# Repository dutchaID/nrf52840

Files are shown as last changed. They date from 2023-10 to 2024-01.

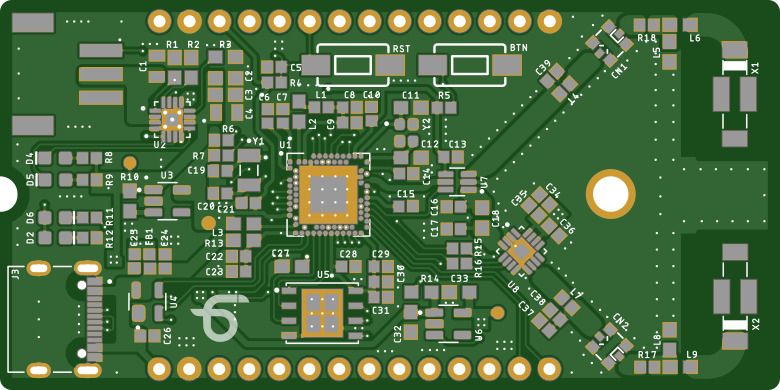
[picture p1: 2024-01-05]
top.jpg

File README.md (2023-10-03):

# Dokumentasi Board NRF52840 V1.0723

﷽

Semoga sehat selalu untuk kita semua.
.
.
.
.
.

# Flash bootloader NRF52840

Bootloader diperlukan karena SOC **NRF52840** dari JLC masih kosong, jadi  fitur-fitur yang ada seperti DFU USB tidak dapat terbaca di PC.

File bootloader bisa menggunakan apa saja, sebagai contoh saya menggunakan bootloader **NRF52840 DK** (PCA10056), kemudian semua config pinout mengikuti board tersebut.

## Peralatan Tempur

- OpenOCD, [gas di sini](https://openocd.org/).
- ST-link V.2
- File bootloader PCA10056
- Arduino IDE, [gas di sini](https://www.arduino.cc/en/software).
- Kabel USB type C

## Langkah-Langkah

1. Install semua peralatan tempurnya. Pastikan sudah **OK** ya...
2. Hubungkan board `NRF52840` dengan `ST-Link V.2` via SWD.
	> */3V3*
	> */GND*
	> */SWCLK*
	> */SWDIO/*
3. Buka Terminal:
    - Cek versi `openocd`,
       >*> openocd -v*
    - Run `openocd`, direktori nya disesuaikan ya...
       >*> openocd -f share/openocd/scripts/interface/stlink.cfg -f share/openocd/scripts/target/nrf52.cfg*
    - `Openocd` sekarang sudah running. Sekarang kita buka terminal lagi untuk menggunakan `telnet`.
       >*> telnet localhost 4444*
    - `Stop execution` bisa gunakan, 
       > *> halt*
    - Hapus `flash` memory,
       > *> nrf5 mass_erase*
    - `Flash NRF52840`,
       > *> program /your/path/to/the/pca10056_bootloader-0.6.2_s140_6.1.1.hex verify*
    - Resume the execution,
       > *> resume*
       
4. Jika berhasil maka pada `Device Manager`, board akan terbaca sebagai *`USB Serial Device(COM...)`*
5. Untuk masuk ke mode `DFU` tekan 2 kali tombol `reset`.

## Pemrograman NRF52840 menggunakan Arduino IDE
1. Buka Arduino IDE, lalu pilih tab `File` dan pilih `Preferences` dan masukkan URL berikut:
    >*https://adafruit.github.io/arduino-board-index/package_adafruit_index.json*
2. Restart Arduino IDE.
3. Pilih `Tools` > `Board` > `Board Manager`. Kemudian pada textbox filter pencarian filter dengan `NRF` dan install `Arduino nRF52 Boars` dan `Adafruit nRF52`.
4. Setelah selesai, silahkan digasken ngodingnya... (saya mencoba dengan program template `bleuart`).....

## Config Pin Board NRF52840

- On board LED `P0.11`, active `LOW`.
- On board button `P1.10`, active `LOW`.
- Switch RF PE4259 `P1.06`, active `HIGH`, lebih detail lihat datasheet.
- Front end RF RFX2401C, RX Enable `P1.04` dan TX Enable `P1.05`, lebih detail lihat datasheet.

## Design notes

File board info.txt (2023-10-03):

> Bluefruit 52 HW Info
 
> MAC Address: E3:32:7:18:24:33
> Device ID  : A3299C384744D933
> MCU Variant: nRF52840 0x41414430
> Memory     : Flash = 1024 KB, RAM = 256 KB

> led P0.11 > 11
> btn P1.10 > 42

> swrf P1.06 > 38 
> txen P1.05 > 37
> rxen P1.04 > 36

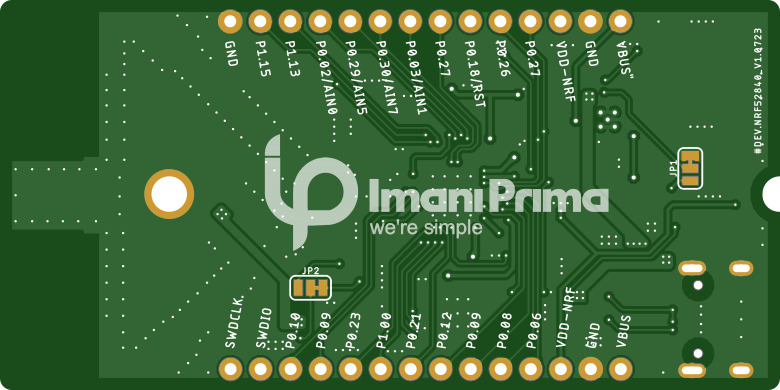
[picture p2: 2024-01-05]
bottom.jpg

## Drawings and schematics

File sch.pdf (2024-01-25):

# P0.02/AIN0 P⁰.02/AIN⁰

# P0.03/AIN1 P⁰.03/AIN¹

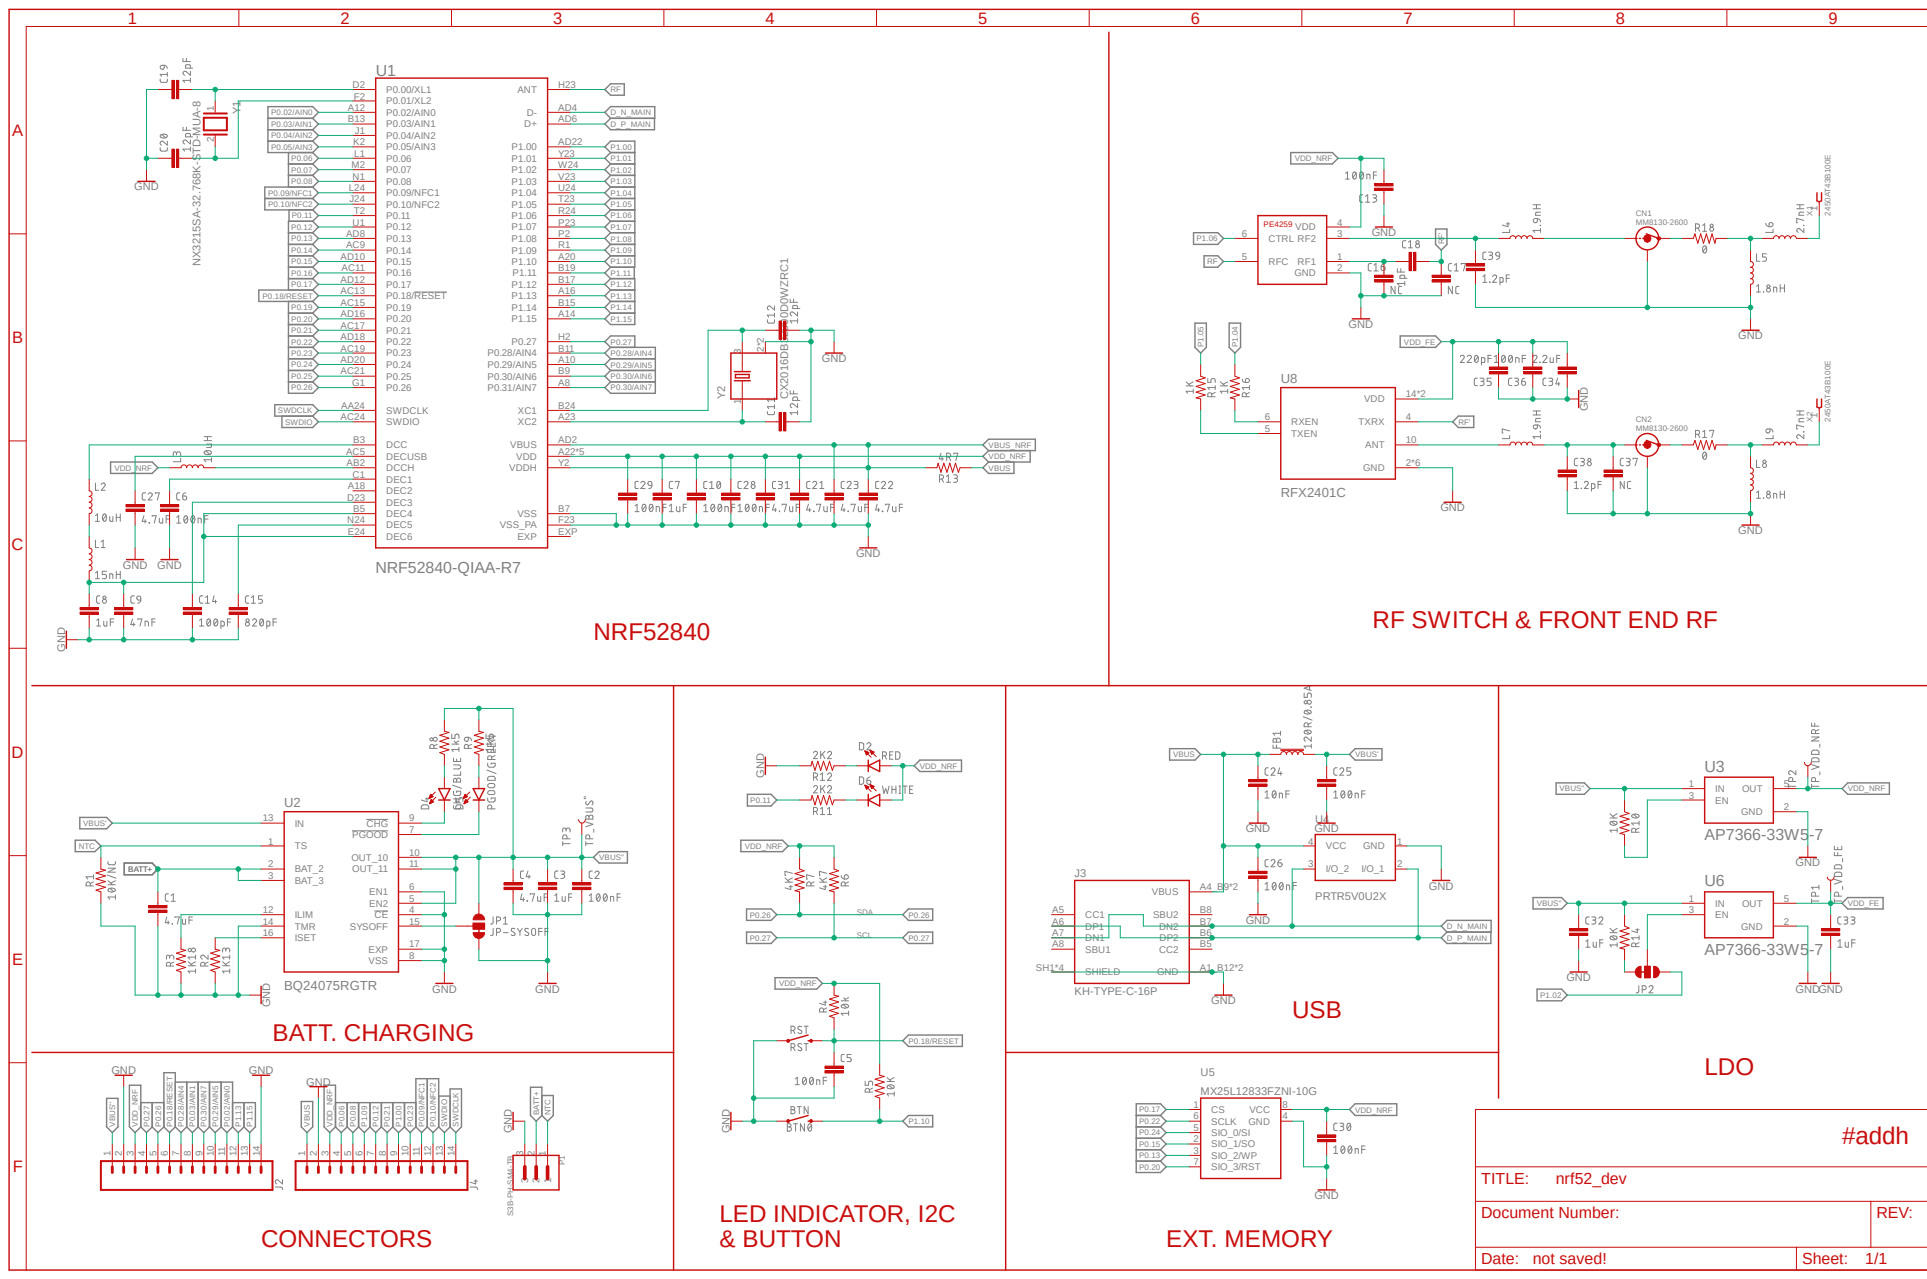
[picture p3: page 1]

P0.04/AIN2 | P0.05/AIN3 K2 | PE4259 A

GND GND

VDD_NRF | DEC1 C1

GND S³B⁻PH⁻SM⁴⁻TB GND

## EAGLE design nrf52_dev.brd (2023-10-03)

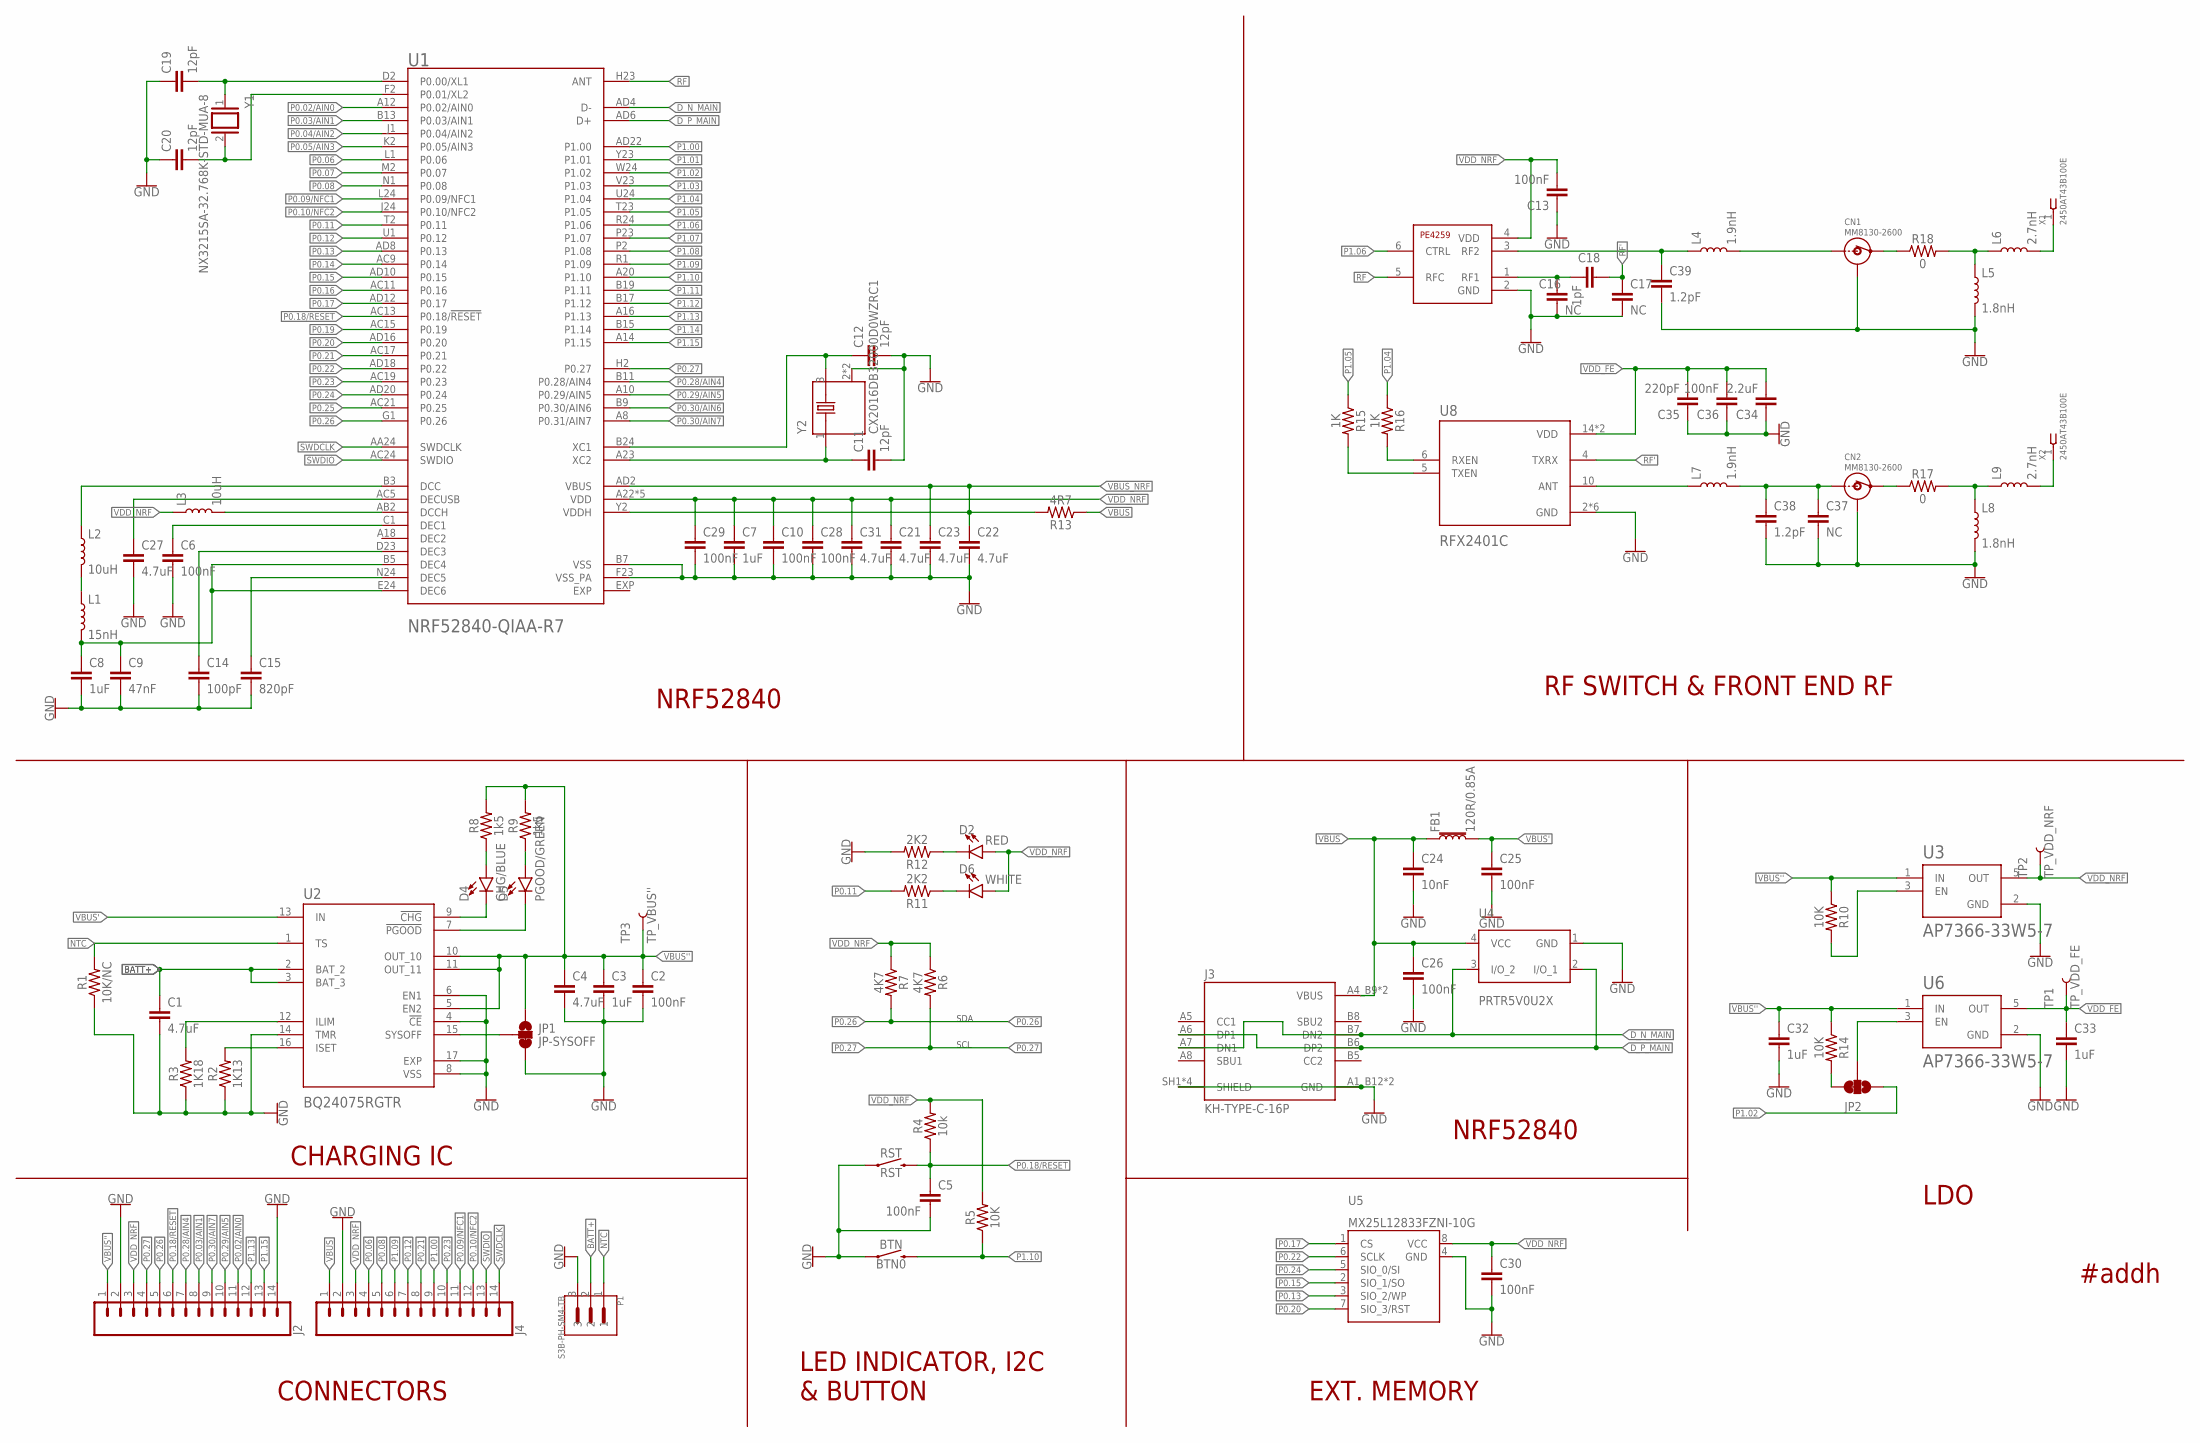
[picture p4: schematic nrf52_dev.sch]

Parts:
BTN: BTN0; TACTILE_SWITCH_SMD_6.0X3.5MM
C1, C4: 4.7uF; 0805
C2: 100nF; 0603
C3, C32, C33: 1uF; 0603
C5, C6, C10, C13, C25, C26, C28, C29, C30, C36: 100nF; 0402
C7, C8: 1uF; 0402
C9: 47nF; 0402
C11, C12: 12pF; 0603
C14: 100pF; 0402
C15: 820pF; 0402
C16, C17, C37: NC; 0402
C18: 1pF; 0603
C19, C20: 12pF; 0402
C21, C22, C23, C31: 4.7uF; 0402
C24: 10nF; 0402
C27: 4.7uF; 0603
C34: 2.2uF; 0402
C35: 220pF; 0402
C38, C39: 1.2pF; 0402
CN1, CN2: MM8130-2600
D2: RED; LED-0603
D4: CHG/BLUE; LED-0603
D5: PGOOD/GREEN; LED-0603
D6: WHITE; LED-0603
FB1: 120R/0.85A; 0402
J2, J4: CONN_14NO_SILK; 1X14_NO_SILK
J3: KH-TYPE-C-16P; KINGHELM_KH-TYPE-C-16P
JP1: JP-SYSOFF; SMT-JUMPER_3_1-NC_TRACE_SILK
JP2: JP_EN1; SMT-JUMPER_3_1-NC_TRACE_SILK
L1: 15nH; 0402
L2, L3: 10uH; 0603
L4, L7: 1.9nH; 0402
L5, L8: 1.8nH; 0603
L6, L9: 2.7nH; 0603
P1: S3B-PH-SM4-TB; JST_S3B-PH-SM4-TB
R1: 10K/NC; 0603
R2: 1K13; 0603
R3: 1K18; 0603
R4: 10k; 0402
R5: 10K; 0402
R6, R7: 4K7; 0402
R8, R9: 1k5; 0402
R10, R14: 10K; 0603
R11, R12: 2K2; 0402
R13: 4R7; 0603
R15, R16: 1K; 0402
R17, R18: 0; 0402
RST: RST; TACTILE_SWITCH_SMD_6.0X3.5MM
TP1: TP_VDD_FE; PAD.03X.04
TP2: TP_VDD_NRF; PAD.03X.04
TP3: TP_VBUS''; PAD.03X.04
U1: NRF52840-QIAA-R7; NORDIC_NRF52840-QIAA-R7
U2: BQ24075RGTR; QFN50P300X300X100-17N
U3, U6: AP7366-33W5-7; SOT95P285X140-5N
U4: PRTR5V0U2X; SOT190P230X110-4N
U5: MX25L12833FZNI-10G; SON127P500X600X80-9N
U7: PE4259; SOT65P210X110-6N
U8: RFX2401C; QFN50P300X300X60-17N
X1, X2: 2450AT43B100E; 2450AT43B100
Y1: NX3215SA-32.768K-STD-MUA-8; XTAL_NX3215SA-32.768K-STD-MUA-8
Y2: CX2016DB32000D0WZRC1; OSCCC200X160X45N

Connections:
BATT+: C1.1, P1.2, U2.2 (BAT_2), U2.3 (BAT_3)
DEC2: U1.A18 (DEC2)
D_N_MAIN: J3.A7 (DN1), J3.B7 (DN2), U1.AD4 (D-), U4.3 (I/O_2)
D_P_MAIN: J3.A6 (DP1), J3.B6 (DP2), U1.AD6 (D+), U4.2 (I/O_1)
EXP: U1.EXP
GND: BTN.1, C1.2, C2.2, C3.2, C4.2, C5.2, C6.2, C7.2, C8.2, C9.2, C10.2, C11.2, C12.2, C13.1, C14.2, C15.2, C16.2, C17.2, C19.1, C20.1, C21.2, C22.2, C23.2, C24.2, C25.2, C26.2, C27.2, C28.2, C29.2, C30.2, C31.2, C32.2, C33.2, C34.1, C35.1, C36.1, C37.2, C38.2, C39.2, CN1.1, CN1.2, CN1.3, CN1.4, CN2.1, CN2.2, CN2.3, CN2.4, J2.2, J2.14, J3.A1_B12 (GND), J3.A12_B1 (GND), J3.SH1 (SHIELD), J3.SH2 (SHIELD), J3.SH3 (SHIELD), J3.SH4 (SHIELD), J4.2, JP1.3, L5.2, L8.2, P1.3, R1.1, R2.1, R3.1, R12.2, RST.1, U1.B7 (VSS), U1.F23 (VSS_PA), U2.4 (!CE), U2.6 (EN1), U2.8 (VSS), U2.14 (TMR), U2.17 (EXP), U3.2 (GND), U4.1 (GND), U5.4 (GND), U6.2 (GND), U7.2 (GND), U8.2 (GND), U8.3 (GND), U8.8 (GND), U8.9 (GND), U8.11 (GND), U8.17 (GND), Y2.2 (GND), Y2.4 (GND)
unnamed: JP2.2, U6.3 (EN)
unnamed: C27.1, U1.AC5 (DECUSB)
unnamed: JP2.3, R14.2
unnamed: D4.C, U2.9 (!CHG)
unnamed: L3.2, U1.AB2 (DCCH)
unnamed: L1.1, L2.2
unnamed: C6.1, U1.C1 (DEC1)
unnamed: L2.1, U1.B3 (DCC)
unnamed: C20.2, U1.F2 (P0.01/XL2), Y1.2
unnamed: C14.1, U1.D23 (DEC3)
unnamed: C15.1, U1.N24 (DEC5)
unnamed: C8.1, C9.1, L1.2, U1.B5 (DEC4), U1.E24 (DEC6)
unnamed: C19.2, U1.D2 (P0.00/XL1), Y1.1
unnamed: C11.1, U1.A23 (XC2), Y2.1 (HOT_1)
unnamed: C12.1, U1.B24 (XC1), Y2.3 (HOT_3)
unnamed: R16.2, U8.6 (RXEN)
unnamed: R15.2, U8.5 (TXEN)
unnamed: D6.C, R11.1
unnamed: D5.C, U2.7 (!PGOOD)
unnamed: R10.2, U3.3 (EN)
unnamed: D2.C, R12.1
unnamed: C16.1, C18.2, U7.1 (RF1)
unnamed: CN1.OUT, R18.1
unnamed: R2.2, U2.16 (ISET)
unnamed: L5.1, L6.1, R18.2
unnamed: JP1.2, U2.15 (SYSOFF)
unnamed: L6.2, X1.1
unnamed: R3.2, U2.12 (ILIM)
unnamed: D4.A, R8.1
unnamed: D5.A, R9.1
unnamed: CN1.IN, L4.2
unnamed: C39.1, L4.1, U7.3 (RF2)
unnamed: C37.1, C38.1, CN2.IN, L7.2
unnamed: CN2.OUT, R17.1
unnamed: L8.1, L9.1, R17.2
unnamed: L9.2, X2.1
unnamed: L7.1, U8.10 (ANT)
NTC: P1.1, R1.2, U2.1 (TS)
P0.02/AIN0: J2.11, U1.A12 (P0.02/AIN0)
P0.03/AIN1: J2.8, U1.B13 (P0.03/AIN1)
P0.04/AIN2: U1.J1 (P0.04/AIN2)
P0.05/AIN3: U1.K2 (P0.05/AIN3)
P0.06: J4.4, U1.L1 (P0.06)
P0.07: U1.M2 (P0.07)
P0.08: J4.5, U1.N1 (P0.08)
P0.09/NFC1: J4.11, U1.L24 (P0.09/NFC1)
P0.10/NFC2: J4.12, U1.J24 (P0.10/NFC2)
P0.11: R11.2, U1.T2 (P0.11)
P0.12: J4.7, U1.U1 (P0.12)
P0.13: U1.AD8 (P0.13), U5.3 (SIO_2/WP)
P0.14: U1.AC9 (P0.14)
P0.15: U1.AD10 (P0.15), U5.2 (SIO_1/SO)
P0.16: U1.AC11 (P0.16)
P0.17: U1.AD12 (P0.17), U5.1 (CS)
P0.18/RESET: C5.1, J2.6, R4.1, RST.2, U1.AC13 (P0.18/!RESET)
P0.19: U1.AC15 (P0.19)
P0.20: U1.AD16 (P0.20), U5.7 (SIO_3/RST)
P0.21: J4.8, U1.AC17 (P0.21)
P0.22: U1.AD18 (P0.22), U5.6 (SCLK)
P0.23: J4.10, U1.AC19 (P0.23)
P0.24: U1.AD20 (P0.24), U5.5 (SIO_0/SI)
P0.25: U1.AC21 (P0.25)
P0.26: J2.5, R7.2, U1.G1 (P0.26)
P0.27: J2.4, R6.2, U1.H2 (P0.27)
P0.28/AIN4: J2.7, U1.B11 (P0.28/AIN4)
P0.29/AIN5: J2.10, U1.A10 (P0.29/AIN5)
P0.30/AIN6: U1.B9 (P0.30/AIN6)
P0.30/AIN7: J2.9, U1.A8 (P0.31/AIN7)
P1.00: J4.9, U1.AD22 (P1.00)
P1.01: U1.Y23 (P1.01)
P1.02: JP2.1, U1.W24 (P1.02)
P1.03: U1.V23 (P1.03)
P1.04: R16.1, U1.U24 (P1.04)
P1.05: R15.1, U1.T23 (P1.05)
P1.06: U1.R24 (P1.06), U7.6 (CTRL)
P1.07: U1.P23 (P1.07)
P1.08: U1.P2 (P1.08)
P1.09: J4.6, U1.R1 (P1.09)
P1.10: BTN.2, R5.1, U1.A20 (P1.10)
P1.11: U1.B19 (P1.11)
P1.12: U1.B17 (P1.12)
P1.13: J2.12, U1.A16 (P1.13)
P1.14: U1.B15 (P1.14)
P1.15: J2.13, U1.A14 (P1.15)
RF: U1.H23 (ANT), U7.5 (RFC)
RF': C17.1, C18.1, U8.4 (TXRX)
SWDCLK: J4.14, U1.AA24 (SWDCLK)
SWDIO: J4.13, U1.AC24 (SWDIO)
VBUS: C24.1, C26.1, FB1.1, J3.A4_B9 (VBUS), J3.A9_B4 (VBUS), J4.1, R13.1, U4.4 (VCC)
VBUS': C25.1, FB1.2, U2.13 (IN)
VBUS'': C2.1, C3.1, C4.1, C32.1, J2.1, JP1.1, R8.2, R9.2, R10.1, R14.1, TP3.P$1, U2.5 (EN2), U2.10 (OUT_10), U2.11 (OUT_11), U3.1 (IN), U6.1 (IN)
VBUS_NRF: C22.1, C23.1, R13.2, U1.AD2 (VBUS), U1.Y2 (VDDH)
VDD_FE: C33.1, C34.2, C35.2, C36.2, TP1.P$1, U6.5 (OUT), U8.14 (VDD), U8.16 (VDD)
VDD_NRF: C7.1, C10.1, C13.2, C21.1, C28.1, C29.1, C30.1, C31.1, D2.A, D6.A, J2.3, J4.3, L3.1, R4.2, R5.2, R6.1, R7.1, TP2.P$1, U1.A22 (VDD), U1.AD14 (VDD), U1.AD23 (VDD), U1.B1 (VDD), U1.W1 (VDD), U3.5 (OUT), U5.8 (VCC), U7.4 (VDD)

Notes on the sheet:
SDA
SCL
NRF52840
RF SWITCH & FRONT END RF
CHARGING IC
CONNECTORS
LED INDICATOR, I2C & BUTTON
LDO
EXT. MEMORY
#addh

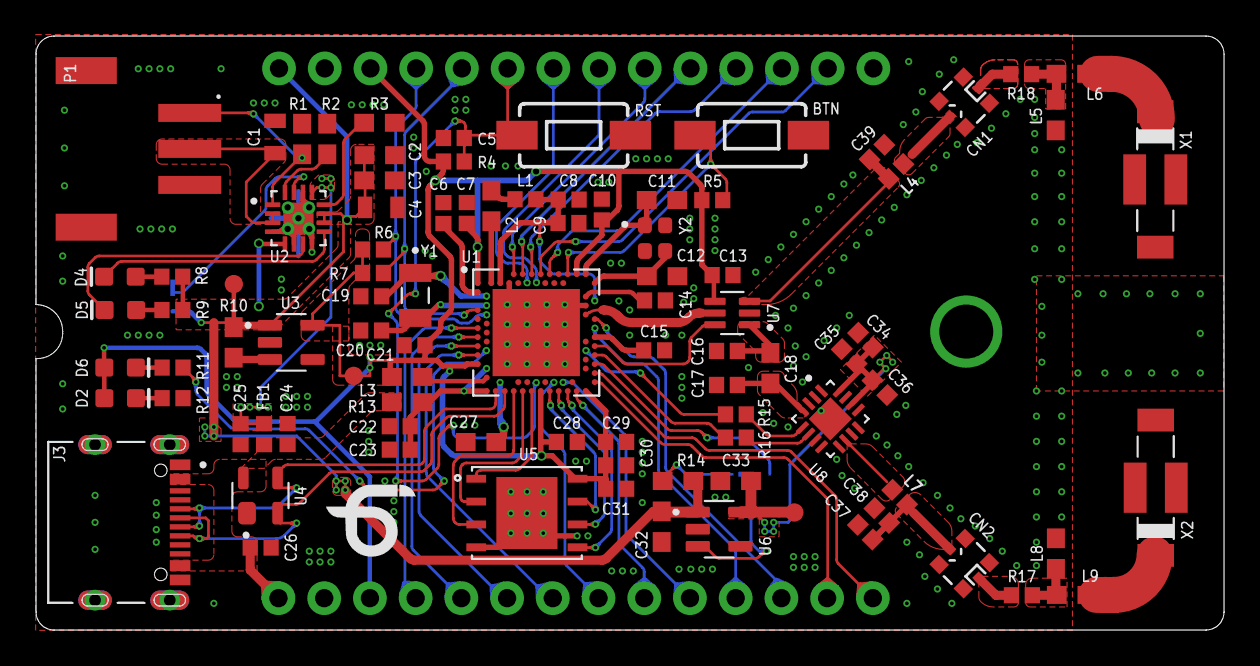
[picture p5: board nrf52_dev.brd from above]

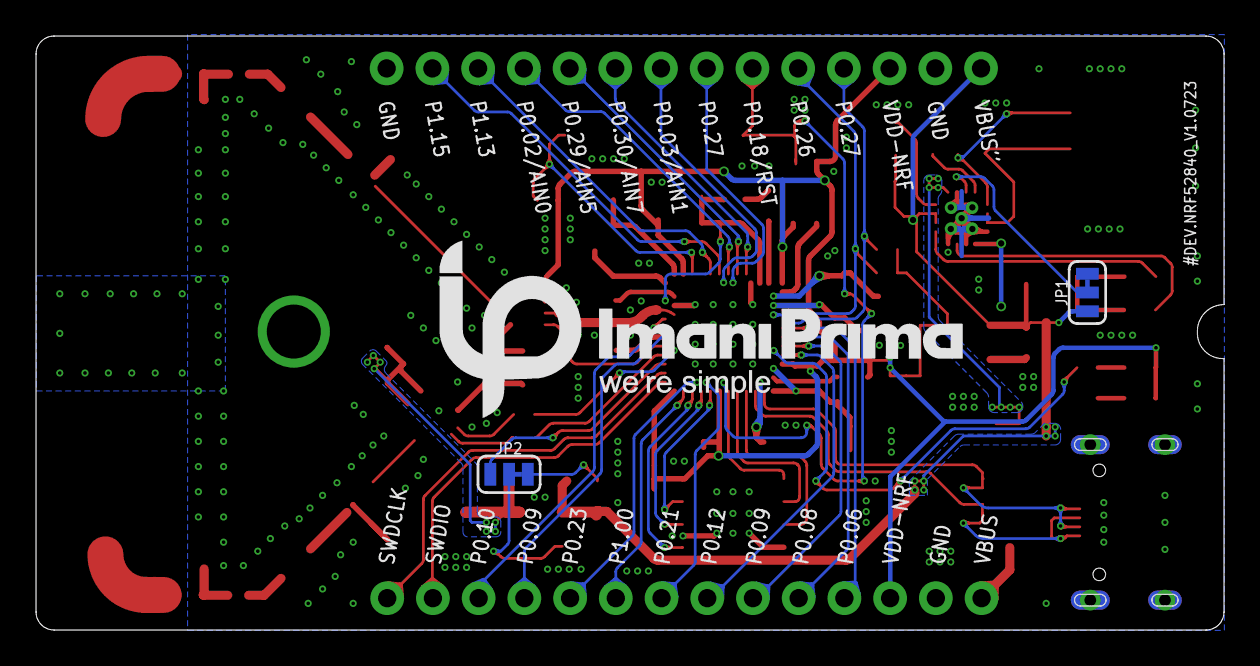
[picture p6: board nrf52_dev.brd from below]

Board: 2 copper layers, 66.0 x 33.0 mm, 98 parts (3 on the bottom side), 83 nets.

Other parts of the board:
U$1: IP_S
U$3: IPS

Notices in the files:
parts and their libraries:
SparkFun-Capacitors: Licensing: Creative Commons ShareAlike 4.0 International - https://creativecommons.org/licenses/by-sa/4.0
